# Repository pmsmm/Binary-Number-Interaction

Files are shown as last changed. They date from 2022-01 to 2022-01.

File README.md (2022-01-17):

# Binary Number Interaction

The Binary Number Interaction is a mini game that was developed for my Master Thesis "Developing a Support Infrastructure for an Escape The Room and Peddy Paper Games". 

This mini game, or interaction as I so call it, was developed to be part of an Escape the Room game that was also developed as part of my thesis. Since this interaction can work as a standalone mini game I decided to place it here for anyone interested in using it.

## List of Components
- Toggle Switch (5x);
- 4-Digit 7-Segment Display (1x);
- Arduino Nano (1x);
- 220Ω Resistor (5x);

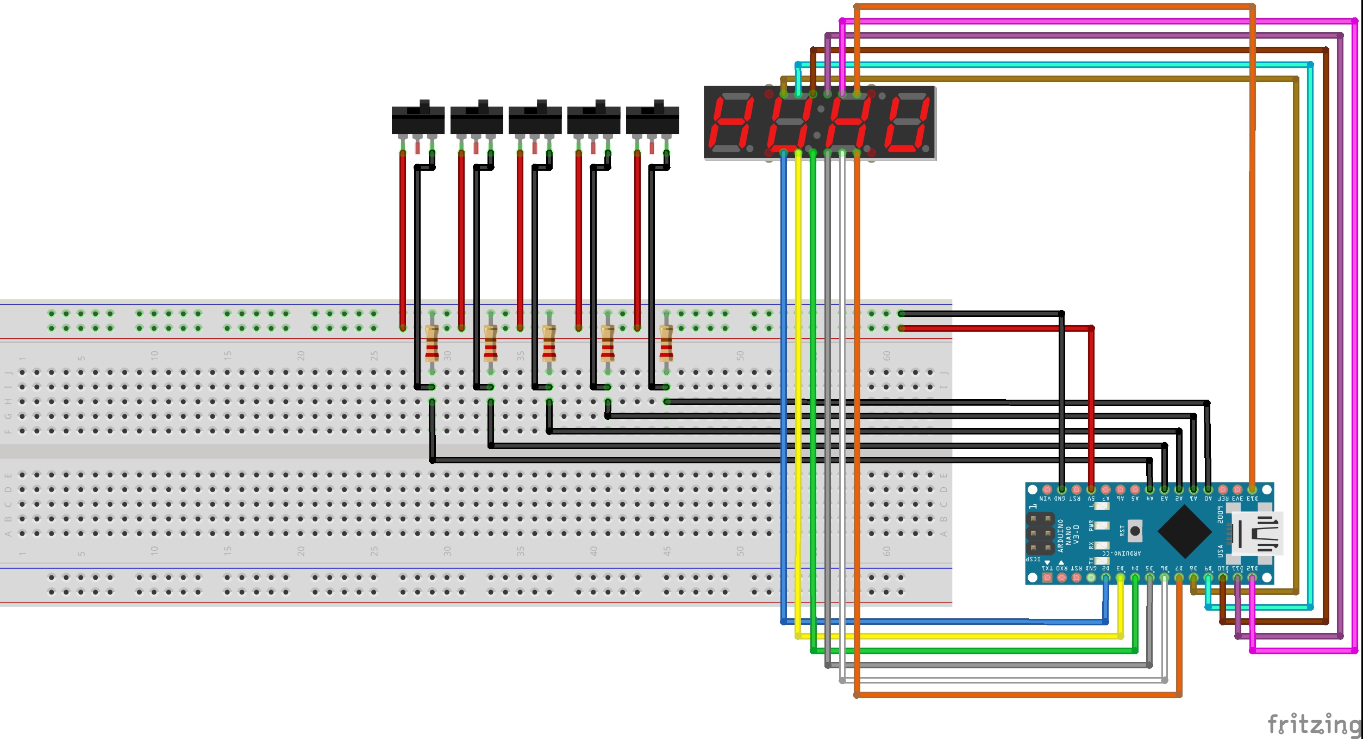
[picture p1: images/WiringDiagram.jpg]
The Wiring Diagram of the Binary Number Interaction


In order to fully assemble the Interaction, so as to look like the picture below, you will also need to 3D Print the enclosure which is divided into two parts that can be found [here](enclosure/).

The Interaction Fully Assembled

## The Purpose of The Game

The way this game works is very simple, in the 4-Digit 7-Segment Display a number, between 1 and 31, appears (This limitation was imposed due to the number of toggle switches used in the making of the interaction) and the player must convert that decimal number into its binary equivalent using the toggle switches.

Each switch corresponds to the significance of the bit with the far left switch corresponding to the most significant bit (2^4) and the far right switch corresponding to the least significant bit (2^0).

### Example

As an example lets say that the number **27** appeared on the display. The toggle switches all **start in the OFF position (flipped down)**. To complete this mini game you will have to flip up the switches to match the following setup:

| Switch 4 | Switch 3 | Switch 2 | Switch 1 | Switch 0
| :---: | :---: | :---: | :---: | :---: |
| ON | ON | OFF | ON | ON |

This setup is equivalent to the binary number 11011 which is equal to the decimal number 27.

## Instructions

First start by uploading the code to your Arduino Nano (This is the one I used so I can only guarantee proper working with this micro-controller). 

### Starting the Game

To start the mini game you must first type in the Arduino IDE serial monitor the following:

- `COM:START;ID:123456789`

When you correctly solve the mini game it will send a message to the serial monitor saying the following: 

> `COM:INTERACTION_SOLVED;MSG:User Introduced Correct Binary Number;PNT:2000`

## WARNING

The source code for this interaction contains a lot of logic that was made to communicate with the infrastructure that was developed for my thesis and therefor it is not as clean as it could be when compared to a mini game that is developed with the intent of being used by the Arduino IDE directly.

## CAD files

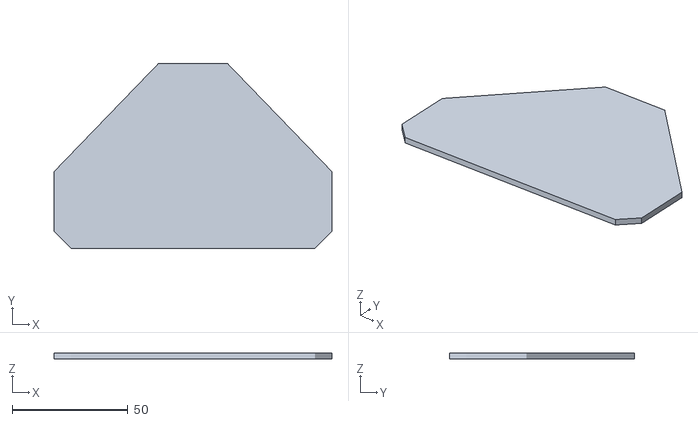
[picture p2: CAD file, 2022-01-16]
enclosure/Bottom.stl
120.0 x 80.0 x 2.50

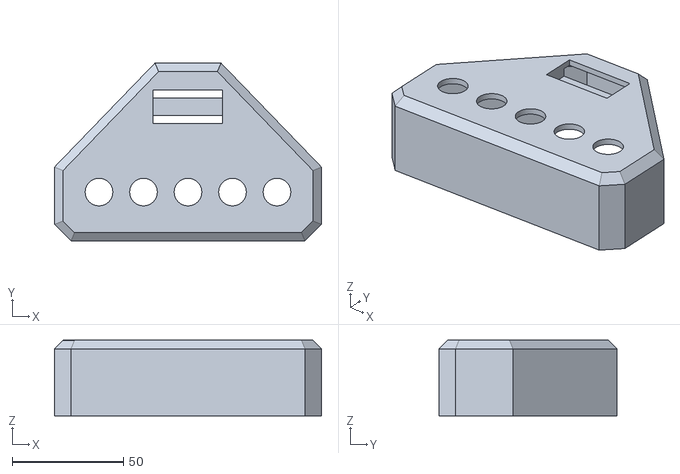
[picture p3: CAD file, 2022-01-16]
enclosure/Top.stl
120.0 x 80.0 x 34.0

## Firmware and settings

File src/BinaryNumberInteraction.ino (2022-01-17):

#define Dig1 13
#define Dig2 10
#define Dig3 9
#define Dig4 2
#define DIGIT_ON LOW
#define DIGIT_OFF HIGH
#define DISPLAY_BRIGHTNESS 1
boolean duiz = false;
boolean hon = false;
#define segA 12
#define segB 8
#define segC 4
#define segD 6
#define segE 7
#define segF 11
#define segG 3
#define segPD = 5;

byte const numBits = 5;
uint8_t numberToConvertToBinary;
byte switches[numBits] = {A4, A3, A0, A1, A2}; //From most significant to least significat bit
byte fourDigitSevenSegmentDisplay[12] = {2, 3, 4, 5, 6, 7, 8, 9, 10, 11, 12, 13};
byte binaryNumber[numBits];

bool INTERACTION_SOLVED, INTERACTION_RUNNING;

void setup() {
  Serial.begin(9600);
  randomSeed(analogRead(A7));
  for (byte i = 0; i < numBits; i++) {
    pinMode(switches[i], INPUT);
  }
  pinMode(segA, OUTPUT);
  pinMode(segB, OUTPUT);
  pinMode(segC, OUTPUT);
  pinMode(segD, OUTPUT);
  pinMode(segE, OUTPUT);
  pinMode(segF, OUTPUT);
  pinMode(segG, OUTPUT);
  pinMode(Dig1, OUTPUT);
  pinMode(Dig2, OUTPUT);
  pinMode(Dig3, OUTPUT);
  pinMode(Dig4, OUTPUT);
}

void loop() {
  if (!Serial) {
    Serial.begin(9600);
  }
  if (Serial.available()) {
    processSerialMessage();
  }
  if (INTERACTION_SOLVED == false && INTERACTION_RUNNING == true) {
    gameLoop();
  }
}

void gameLoop() {
  displayNumber(numberToConvertToBinary);
  for (byte i = 0; i < numBits; i++) {
    if ((!digitalRead(switches[i])) == HIGH) {
      //Print the number corresponding to the current combination of switches maybe;
    }
  }
  if (checkWinning()) {
    Serial.println("COM:INTERACTION_SOLVED;MSG:User Introduced Correct Binary Number;PNT:2000");
    Serial.flush();
    uint8_t times = 0;
    while (times < 5) {
      digitalWrite(Dig1, DIGIT_ON);
      lightNumber(8);
      digitalWrite(Dig2, DIGIT_ON);
      lightNumber(8);
      digitalWrite(Dig3, DIGIT_ON);
      lightNumber(8);
      digitalWrite(Dig4, DIGIT_ON);
      lightNumber(8);
      delay(500);
      digitalWrite(Dig4, DIGIT_OFF);
      digitalWrite(Dig3, DIGIT_OFF);
      digitalWrite(Dig2, DIGIT_OFF);
      digitalWrite(Dig1, DIGIT_OFF);
      delay(500);
      times++;
    }
  }
}

void processSerialMessage() {
  const int BUFF_SIZE = 64; // make it big enough to hold your longest command
  static char buffer[BUFF_SIZE + 1]; // +1 allows space for the null terminator
  static int length = 0; // number of characters currently in the buffer

  char c = Serial.read();
  if ((c == '\r') || (c == '\n')) {
    // end-of-line received
    if (length > 0) {
      tokenizeReceivedMessage(buffer);
    }
    length = 0;
  } else {
    if (length < BUFF_SIZE) {
      buffer[length++] = c; // append the received character to the array
      buffer[length] = 0; // append the null terminator
    }
  }
}

void tokenizeReceivedMessage(char *msg) {
  const int COMMAND_PAIRS = 10;
  char* tokenizedString[COMMAND_PAIRS + 1];
  int index = 0;

  char* command = strtok(msg, ";");
  while (command != 0) {
    char* separator = strchr(command, ':');
    if (separator != 0) {
      *separator = 0;
      tokenizedString[index++] = command;
      ++separator;
      tokenizedString[index++] = separator;
    }
    command = strtok(0, ";");
  }
  tokenizedString[index] = 0;

  processReceivedMessage(tokenizedString);
}

void processReceivedMessage(char** command) {
  if (strcmp(command[1], "START") == 0) {
    startSequence(command[3]);
  } else if (strcmp(command[1], "PAUSE") == 0) {
    pauseSequence(command[3]);
  } else if (strcmp(command[1], "STOP") == 0) {
    stopSequence(command[3]);
  } else if (strcmp(command[1], "INTERACTION_SOLVED_ACK") == 0) {
    setInteractionSolved();
  } else if (strcmp(command[1], "PING") == 0) {
    ping(command[3]);
  } else if (strcmp(command[1], "BAUD") == 0) {
    setBaudRate(atoi(command[3]), command[5]);
  } else if (strcmp(command[1], "SETUP") == 0) {
    Serial.println("COM:SETUP;INT_NAME:Binary Number Interaction;BAUD:9600");
    Serial.flush();
  }
}

void startSequence(char* TIMESTAMP) {
  numberToConvertToBinary = random(1, 32);
  for (byte i = 0; i < numBits; i++) {
    byte state = bitRead(numberToConvertToBinary, i);
    binaryNumber[((numBits - 1) - i)] = state;
  }
  INTERACTION_SOLVED = false;
  INTERACTION_RUNNING = true;
  Serial.print("COM:START_ACK;MSG:");
  for (uint8_t i = 0; i < numBits; i++) {
    Serial.print(binaryNumber[i]);
  }
  Serial.print(";ID:");
  Serial.print(TIMESTAMP);
  Serial.print("\r\n");
  Serial.flush();
}

void pauseSequence(char* TIMESTAMP) {
  INTERACTION_RUNNING = !INTERACTION_RUNNING;
  if (INTERACTION_RUNNING) {
    Serial.print("COM:PAUSE_ACK;MSG:Device is now running;ID:");
  } else {
    Serial.print("COM:PAUSE_ACK;MSG:Device is now paused;ID:");
  }
  Serial.print(TIMESTAMP);
  Serial.print("\r\n");
  Serial.flush();
}

void stopSequence(char* TIMESTAMP) {
  INTERACTION_RUNNING = false;
  Serial.print("COM:STOP_ACK;MSG:Device is now stopped;ID:");
  Serial.print(TIMESTAMP);
  Serial.print("\r\n");
  Serial.flush();
}

void setInteractionSolved() {
  INTERACTION_SOLVED = true;
  INTERACTION_RUNNING = false;
}

void ping(char* TIMESTAMP) {
  Serial.print("COM:PING;MSG:PING;ID:");
  Serial.print(TIMESTAMP);
  Serial.print("\r\n");
  Serial.flush();
}

void setBaudRate(int baudRate, char* TIMESTAMP) {
  Serial.flush();
  Serial.begin(baudRate);
  Serial.print("COM:BAUD_ACK;MSG:The Baud Rate was set to ");
  Serial.print(baudRate);
  Serial.print(";ID:");
  Serial.print(TIMESTAMP);
  Serial.print("\r\n");
  Serial.flush();
}

bool checkWinning() {
  for (byte i = 0; i < numBits; i++) {
    if ((!digitalRead(switches[i])) == binaryNumber[i]) {
      continue;
    } else {
      return false;
    }
  }
  INTERACTION_SOLVED = true;
  return true;
}

void displayNumber(int figur) {
  duiz = false;
  hon = false;
  for (int k = 0; k < 50; k++) { // for loop to slow it down.
    for (int digit = 1 ; digit < 5 ; digit++) { //for loop to place the number in the right digit
      switch (digit) {
        case 1:
          if (figur > 999) {
            digitalWrite(Dig1, DIGIT_ON);
            lightNumber(figur / 1000); // for example 2511 / 1000 = 2
            figur %= 1000; // new value of figur = 511 figur = figur %1000

            delayMicroseconds(DISPLAY_BRIGHTNESS);
            if (figur < 100) {
              duiz = true;
              if (figur < 10) {
                hon = true;

              }

            } else duiz = false;
          }

          break;
        case 2:
          if (duiz == true) {
            digitalWrite(Dig2, DIGIT_ON);
            lightNumber(0);
            delayMicroseconds(DISPLAY_BRIGHTNESS);

          } if (hon == true) {
            break;
          }

          if (figur > 99 && figur < 1000) {
            digitalWrite(Dig2, DIGIT_ON);
            lightNumber(figur / 100);
            figur %= 100;
            delayMicroseconds(DISPLAY_BRIGHTNESS);
            if (figur < 10) {
              hon = true;

            } else hon = false;
          }
          break;
        case 3:
          if (hon == true) {
            digitalWrite(Dig3, DIGIT_ON);
            lightNumber(0);
            delayMicroseconds(DISPLAY_BRIGHTNESS);
            break;
          }

          if (figur > 9 && figur < 100) {
            digitalWrite(Dig3, DIGIT_ON);
            lightNumber(figur / 10);
            figur %= 10;
            delayMicroseconds(DISPLAY_BRIGHTNESS);
          }

          break;
        case 4:
          if (figur < 10) {
            digitalWrite(Dig4, DIGIT_ON);
            lightNumber(figur);
            delayMicroseconds(DISPLAY_BRIGHTNESS);

            break;
          }
      }
      if (digit != 4) {
        //Turn off all segments
        lightNumber(10);
        //Turn off all digits
        digitalWrite(Dig1, DIGIT_OFF);
        digitalWrite(Dig2, DIGIT_OFF);
        digitalWrite(Dig3, DIGIT_OFF);
        digitalWrite(Dig4, DIGIT_OFF);
      }
    }
  }
}

void lightNumber(int numberToDisplay) {
#define SEGMENT_ON HIGH
#define SEGMENT_OFF LOW
  switch (numberToDisplay) {
    case 0:
      digitalWrite(segA, SEGMENT_ON);
      digitalWrite(segB, SEGMENT_ON);
      digitalWrite(segC, SEGMENT_ON);
      digitalWrite(segD, SEGMENT_ON);
      digitalWrite(segE, SEGMENT_ON);
      digitalWrite(segF, SEGMENT_ON);
      digitalWrite(segG, SEGMENT_OFF);
      break;
    case 1:
      digitalWrite(segA, SEGMENT_OFF);
      digitalWrite(segB, SEGMENT_ON);
      digitalWrite(segC, SEGMENT_ON);
      digitalWrite(segD, SEGMENT_OFF);
      digitalWrite(segE, SEGMENT_OFF);
      digitalWrite(segF, SEGMENT_OFF);
      digitalWrite(segG, SEGMENT_OFF);
      break;
    case 2:
      digitalWrite(segA, SEGMENT_ON);
      digitalWrite(segB, SEGMENT_ON);
      digitalWrite(segC, SEGMENT_OFF);
      digitalWrite(segD, SEGMENT_ON);
      digitalWrite(segE, SEGMENT_ON);
      digitalWrite(segF, SEGMENT_OFF);
      digitalWrite(segG, SEGMENT_ON);
      break;
    case 3:
      digitalWrite(segA, SEGMENT_ON);
      digitalWrite(segB, SEGMENT_ON);
      digitalWrite(segC, SEGMENT_ON);
      digitalWrite(segD, SEGMENT_ON);
      digitalWrite(segE, SEGMENT_OFF);
      digitalWrite(segF, SEGMENT_OFF);
      digitalWrite(segG, SEGMENT_ON);
      break;
    case 4:
      digitalWrite(segA, SEGMENT_OFF);
      digitalWrite(segB, SEGMENT_ON);
      digitalWrite(segC, SEGMENT_ON);
      digitalWrite(segD, SEGMENT_OFF);
      digitalWrite(segE, SEGMENT_OFF);
      digitalWrite(segF, SEGMENT_ON);
      digitalWrite(segG, SEGMENT_ON);
      break;
    case 5:
      digitalWrite(segA, SEGMENT_ON);
      digitalWrite(segB, SEGMENT_OFF);
      digitalWrite(segC, SEGMENT_ON);
      digitalWrite(segD, SEGMENT_ON);
      digitalWrite(segE, SEGMENT_OFF);
      digitalWrite(segF, SEGMENT_ON);
      digitalWrite(segG, SEGMENT_ON);
      break;
    case 6:
      digitalWrite(segA, SEGMENT_ON);
      digitalWrite(segB, SEGMENT_OFF);
      digitalWrite(segC, SEGMENT_ON);
      digitalWrite(segD, SEGMENT_ON);
      digitalWrite(segE, SEGMENT_ON);
      digitalWrite(segF, SEGMENT_ON);
      digitalWrite(segG, SEGMENT_ON);
      break;
    case 7:
      digitalWrite(segA, SEGMENT_ON);
      digitalWrite(segB, SEGMENT_ON);
      digitalWrite(segC, SEGMENT_ON);
      digitalWrite(segD, SEGMENT_OFF);
      digitalWrite(segE, SEGMENT_OFF);
      digitalWrite(segF, SEGMENT_OFF);
      digitalWrite(segG, SEGMENT_OFF);
      break;
    case 8:
      digitalWrite(segA, SEGMENT_ON);
      digitalWrite(segB, SEGMENT_ON);
      digitalWrite(segC, SEGMENT_ON);
      digitalWrite(segD, SEGMENT_ON);
      digitalWrite(segE, SEGMENT_ON);
      digitalWrite(segF, SEGMENT_ON);
      digitalWrite(segG, SEGMENT_ON);
      break;
    case 9:
      digitalWrite(segA, SEGMENT_ON);
      digitalWrite(segB, SEGMENT_ON);
      digitalWrite(segC, SEGMENT_ON);
      digitalWrite(segD, SEGMENT_ON);
      digitalWrite(segE, SEGMENT_OFF);
      digitalWrite(segF, SEGMENT_ON);
      digitalWrite(segG, SEGMENT_ON);
      break;
    case 10:
      digitalWrite(segA, SEGMENT_OFF);
      digitalWrite(segB, SEGMENT_OFF);
      digitalWrite(segC, SEGMENT_OFF);
      digitalWrite(segD, SEGMENT_OFF);
      digitalWrite(segE, SEGMENT_OFF);
      digitalWrite(segF, SEGMENT_OFF);
      digitalWrite(segG, SEGMENT_OFF);
      break;
  }
}

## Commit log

2022-01-16 Initial Commit
    Uploaded the Wiring Diagram of the Interaction.
    Uploaded an image of the interaction when it's fully assembled.
    Uploaded the Arduino file with the Interaction Code.
    Uploaded the case of the interaction (Both the bottom and the top of the case that together form the enclosure)
    [Bottom.stl, Top.stl]
2022-01-17 Updated the README.md to include a description of the interaction and usage instructions
    [Bottom.stl, Top.stl]
2022-01-17 Updated Readme.md with Missing Components
    Added the Arduino Nano component that was missing in the list of materials
2022-01-17 Component Addition
    Added the 220Ω resistor component that is required to build the interaction
